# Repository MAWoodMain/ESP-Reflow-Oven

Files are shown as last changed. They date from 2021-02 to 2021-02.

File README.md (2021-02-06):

<!--
*** Thanks for checking out the Best-README-Template. If you have a suggestion
*** that would make this better, please fork the repo and create a pull request
*** or simply open an issue with the tag "enhancement".
*** Thanks again! Now go create something AMAZING! :D
***
***
***
*** To avoid retyping too much info. Do a search and replace for the following:
*** github_username, repo_name, twitter_handle, email, project_title, project_description
-->

<!--
*** This readme is based on the template from this github project
*** https://github.com/othneildrew/Best-README-Template
-->

<!-- PROJECT SHIELDS -->
<!--
*** I'm using markdown "reference style" links for readability.
*** Reference links are enclosed in brackets [ ] instead of parentheses ( ).
*** See the bottom of this document for the declaration of the reference variables
*** for contributors-url, forks-url, etc. This is an optional, concise syntax you may use.
*** https://www.markdownguide.org/basic-syntax/#reference-style-links
-->

<br />
<p align="center">

  <h3 align="center">ESP Reflow Oven</h3>

  <p align="center">
    A retro fit of a Lidl middle aisle mini oven into a home reflow oven
  </p>
</p>

<!-- TABLE OF CONTENTS -->
<details open="open">
  <summary><h2 style="display: inline-block">Table of Contents</h2></summary>
  <ol>
    <li>
      <a href="#about-the-project">About The Project</a>
      <ul>
        <li><a href="#objectives">Objectives</a></li>
        <li><a href="#component-selection">Component Selection</a></li>
      </ul>
    </li>
    <li>
      <a href="#the-build">The Build</a>
      <ul>
        <li><a href="#components">Components</a></li>
        <li><a href="#assembly">Assembly</a></li>
      </ul>
    </li>
    <li><a href="#the-final-product">The Final Product</a></li>
    <li><a href="#reflections">Reflections</a></li>
    <li><a href="#license">License</a></li>
  </ol>
</details>

<!-- ABOUT THE PROJECT -->
## About The Project
This project came about on a friday night trip to lidl in the UKs second lockdown. I spotted that lidl were selling mini ovens in the middle aisle for a meagre £25 (~$35), having seen many online creators doing their own homemade reflow ovens based on similar toaster ovens I though it would be a worthy weekend project.  
Naturally after getting home from lidl and putting away all the chilled and frozen foods I went straight into a teardown to see how this thing was put together, the original oven had 3 dials on the front:
* Temperature
* Mode (top/bottom/both elements)
* Timer

Under the hood there was practically nothing just a large void in the case with a few wires going to the elements, the temperature control was a simple bimetallic strip temeperature control which seems to operate based on the temperature in the chamber next to the oven? Not sure how that could even work properly, either way its going into the bin. Similar story for the mode switch, it just switches in and out elements based on the selection, this will not be required either.

After they were removed I was left with the mains input going through a thermal fuse and into a timer switch, I will keep the timer switch to I can set an automatic off when using the unit under computer control. Also this timer switch makes a rather satisfying ding sound when it turns off, I would hate to lose such an important feature...

<!-- OBJECTIVES -->
### Objectives
Had only a few key objectives when I started this project:

* All the mechanical components should be 3D printable using FDM technology.

* I wanted to utilise ESPHome as I have been following some creators project using it, and I was keen to give it a go.

* I wanted the SMT components on the PCB to be assembled by JLC assembly, I know this one sounds a bit weird given I am constructing a reflow oven, but it honestly is often cheaper to have components assembled at JLCPCB rather than ordering them, paying shipping for both PCBs and components then organising paste and a stencil. This oven if for when I have to use components not available for this service and for special cases.

* I needed the oven to follow a simple reflow curve, doesn't need to be prefect but it must work for basic board with normal components.

* I also wanted to try out a Nextion display as I had also seen a few videos by [Vaclav Chaloupka](https://www.youtube.com/user/bruxy70) making some cool home assistant home control panels using the modules.

* Finally I wanted to keep all the original products safety features in place so I don't create a major fire hazard.

<!-- COMPONENT SELECTION -->
### Component Selection

I knew this project would involve working with mains electricity so I made sure to choose components with recognisable approvals and safety certifications for the mains side of the electronics. For that reason I chose a [meanwell isolated AC to DC converter](https://www.meanwell.com/Upload/PDF/IRM-05/IRM-05-SPEC.PDF) to power the low voltage side of the electronics.

The heating elements were tested and found to draw around 600 Watts each which in the UK is around 2.5-3 Amps, the switching component selected for this load was a 5 Amp solid state relay. Specifically I made sure to select a zero crossing SSR as with resistive loads it is better for the powerline quality in the house as it avoids harsh mid phase loading. A [CX240D5](http://www.crydom.com/en/products/catalog/cx-series-ac-pcb-mount.pdf) was used as it was easily available and has approvals several reputable approvals (UL, CSA and CE).

A supplementary on board fuse holder and fuse was included in the design just in case the plug fuse is especially slow or overrated.

The low voltage side will be an ESP32, some thermocouple inputs and a DC output to allow for a fan in the future if required to cool the electronics.

For the thermocouple inputs I have very few ICs to choose from as JLC Assembly did not seem to have many available, I settled on the [MAX31855](https://datasheets.maximintegrated.com/en/ds/MAX31855.pdf) which includes cold junction compensation and requires no external components to work aside from basic decoupling. It uses SPI to send data back to the MCU, it has no settings to configure and does not support receiving data over SPI.

The fan output is a 5V power output which consists of a P-Channel MOSFET and a NPN drive transistor for the gate. This output can only support about 0.5A output as the meanwell power supply is only rated for 1A and the ESP32 required 0.5A.

Below is the 3D model of the PCB in the Kicad 3D viewer:

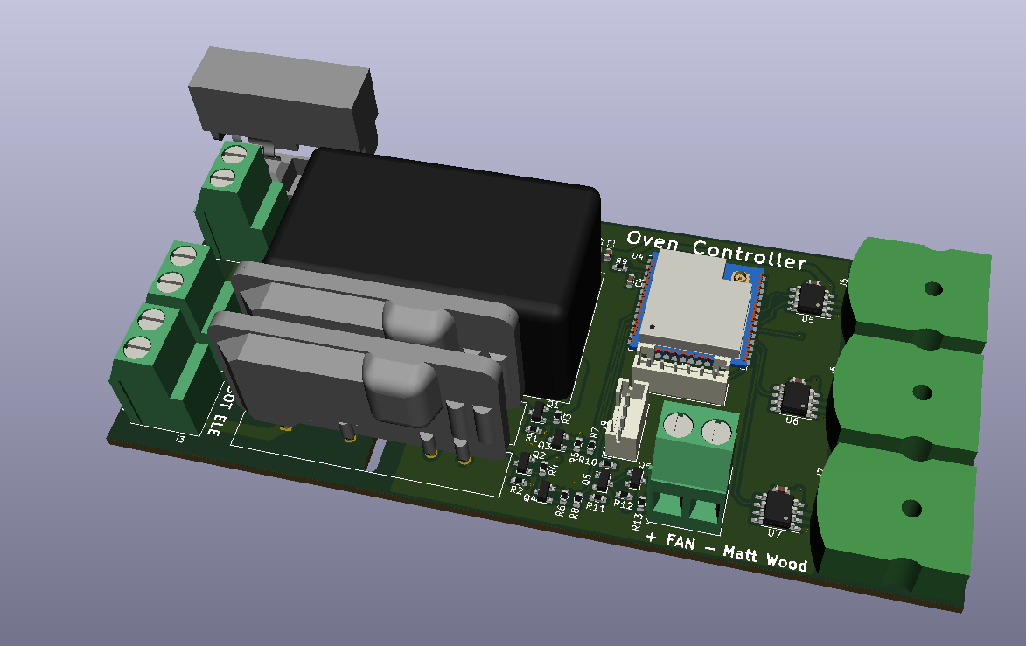
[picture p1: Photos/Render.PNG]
The PCBA


<!-- THE BUILD -->
## The Build

<!-- COMPONENTS -->
### Components

In addition to the assembled PCB discussed above and the 3D printed parts, a few extra components are required:
* 1 x u.FL to SMA pig tail to allow for an external antenna for the WiFi.
* 1 x SMA 2.4 GHz antenna
* 1 x USB to UART module (3.3V logic) to program the ESP and Nextion display
* 1x Nextion NX4832K035 display module
* 1x Custom cable to connect the nextion display to the PCB (JST-PH)
* 2x bead K type thermocouples
* Optional 1x high mass K type thermocouple for chamber air temperature

<!-- ASSEMBLY -->
### Assembly
The PCBs arrived SMT complete from JLCPCB, the THT components were hand soldered in to finish the PCBA off.
At this point it is worth getting the firmware uploaded into the ESP32, after the first firmware is loaded OTA updating is trivial using the ESPHome home assistant plugin.

It is also worth preparing the Nextion display module, I uploaded the firmware to the display using a USB to UART module and the nextion editor software.

As discussed in the project intro the original mode and temperature knobs were removed. 
Next some stand offs were mounted in the space next to the heating chamber to affix the PCB to.
The PCB was mounted and custom cables were crimped to connect up the mains input and heating elements.
Some holes were drilled to allow the thermocouples into the heated chamber one on the top of the right side and one on the bottom.

A hole was drilled for the SMA connector on the top and the u.FL end was plugged into the ESP32 module.

Next the 3D printed LCD mount was screwed into the front panel using the original self tapping screws which held the old controls on. The LCD was itself screwed into the mount using M3x10mm pan head bolts and the cable was run back to the main PCB. The LCD cover was pressed on to finish off the front. I discovered you must take care pressing this cover on as if you press it on too far it triggers the resistive touch screen on the nextion module.

Below is a photo of the electronics compartment, please don't judge the wire runs too heavily as it has been improved since.
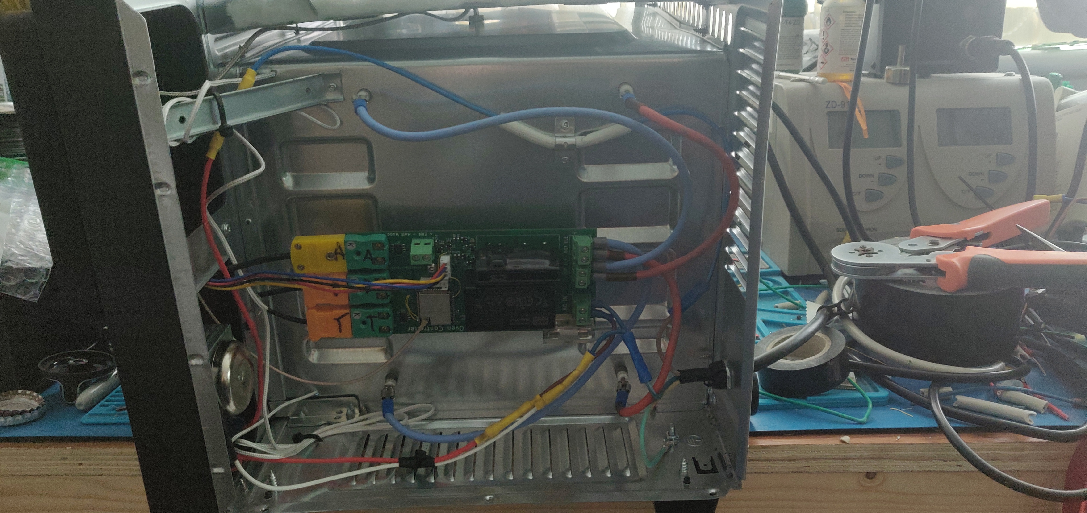
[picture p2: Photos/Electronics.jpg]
Electronics


Once the assembly was complete the PIDs loops require tuning so I attached the top and bottom thermocouples to a blank PCB and ran the auto tune routine for both the top and bottom PID control loops.
These values were saved into the ESPHome YAML so they persist though reboot.

<!-- THE FINAL PRODUCT -->
## The Final Product
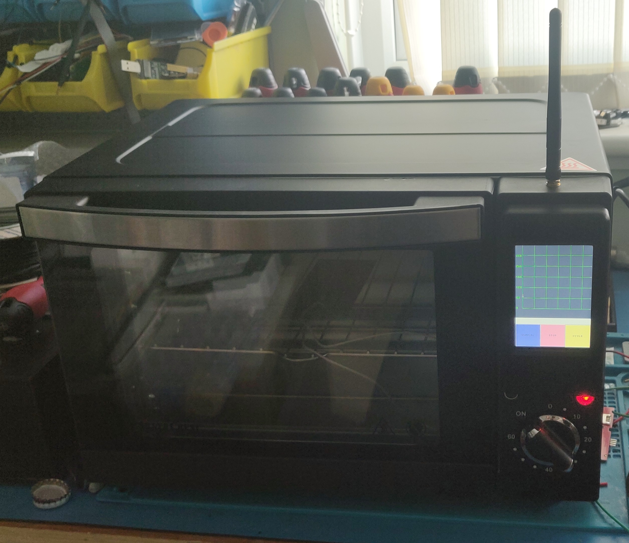
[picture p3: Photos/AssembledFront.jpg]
The final oven

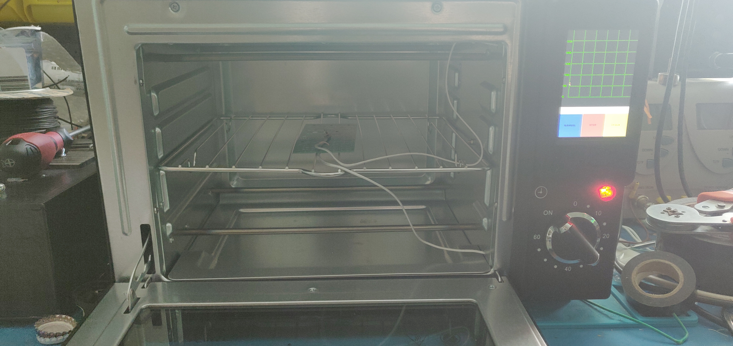
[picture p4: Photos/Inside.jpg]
The inside

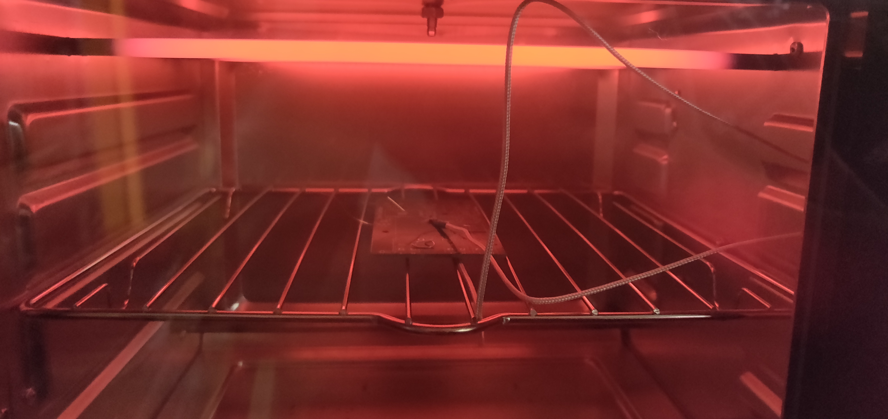
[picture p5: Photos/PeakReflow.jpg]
Mid reflow

<!-- REFLECTIONS -->
## Reflections

I am happy with the final product I think the outside looks very clean and the interface is simple and intuitive.
There are a few issues I ran into during this project:
* Two PID loops, since I went with independent top and bottom heat controls I have two PID loops for the top and bottom systems but since these two systems are used simultaneously they are not independent closed loop systems. The issue with this is that the PID settings do not account properly the other loop existing and thus tend to overshoot the set temperature when they are used together. For reflow I have not found a 5 degree overshoot to be a problem but for some use cases I could see it being an issue. I would propose two possible solutions: You could either combine the two elements and control them as a single large element in a single PID loop or you could use a more sophisticated control system which accounted for the second elements influence.

* Dependence on Home assistant, in the way I am currently controlling it the oven relys on HASS to orchastrate the reflow cycle, if the connection to HASS is lost the oven could be left on at the set temperature for too long. Also it means if HASS is unavailable the cycle button does not work properly. This could be resolved by hard coding the cycle into the ESPHome config, but I have not done this yet.

* Cost, this project was started because of the cheapness of the oven but untimately its cost mostly came in the PCBA price. The total price of the PCB was around £17 for the PCBs from JLC (part assembled) and around £35 of THT parts from Farnell for a total cost of £52 (parts) + £25 (oven) = £77 (~$105). I don't feel I over spent given the capability of this oven but it is slightly more then I though it would cost. The main cost issue was in the farnell parts but this was caused by the safe main voltage components, so it is likely unavoidable.

<!-- LICENSE -->
## License

Distributed under the MIT License. See `LICENSE` for more information.

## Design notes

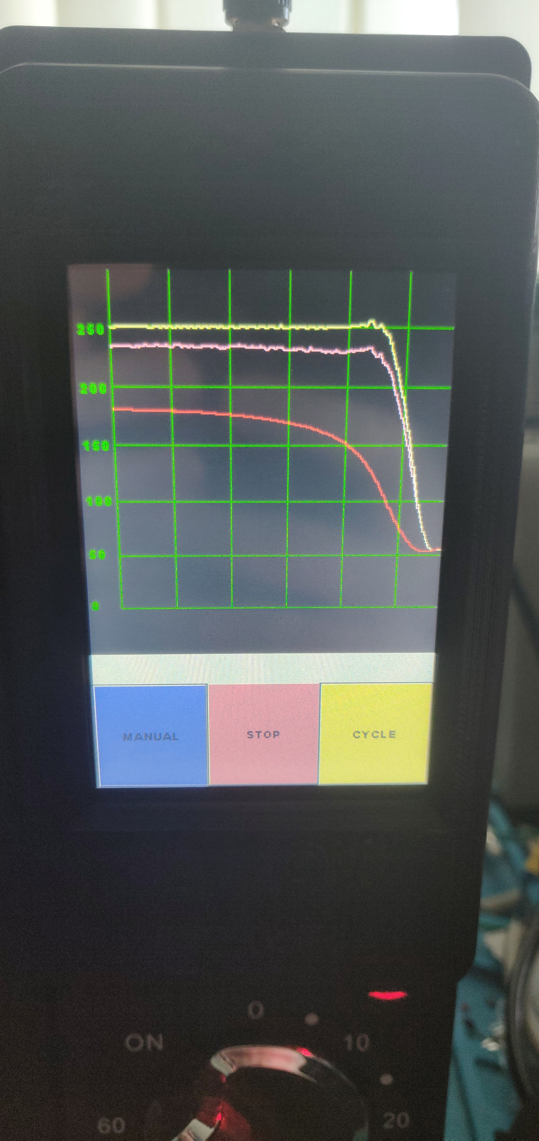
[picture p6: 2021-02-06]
Photos/DisplayGraph.jpg

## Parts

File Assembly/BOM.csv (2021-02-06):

Comment | Designator | Footprint | LCSC Part #
10uF Unpolarized capacitor | C1,C2 | C_0805_2012Metric | C15850
100nF Unpolarized capacitor, small symbol | C3,C4,C5,C6,C7 | C_0603_1608Metric | C14663
696101000002 | J4 | 696101000002
AO3401A -4.0A Id, -30V Vds, P-Channel MOSFET, SOT-23 | Q1,Q2,Q6 | SOT-23 | C15127
BC847 0.1A Ic, 45V Vce, NPN Transistor, SOT-23 | Q3,Q4,Q5 | SOT-23 | C426568
10K Resistor, small symbol | R1,R2,R3,R4,R5,R6,R9,R11,R12,R13 | R_0603_1608Metric | C25804
1K Resistor, small symbol | R7,R8,R10 | R_0603_1608Metric | C21190
AMS1117-3.3 1A Low Dropout regulator, positive, 3.3V fixed output, SOT-223 | U3 | SOT-223-3_TabPin2 | C6186
ESP32-WROOM-32U RF Module, ESP32-D0WD SoC, Wi-Fi 802.11b/g/n, Bluetooth, BLE, 32-bit, 2.7-3.6V, external antenna, SMD | U4 | ESP32-WROOM-32U | C328062
MAX31855KASA Cold Junction K-type Termocouple Interface, SPI, SO8 | U5,U6,U7 | SOIC-8_3.9x4.9mm_P1.27mm | C52028

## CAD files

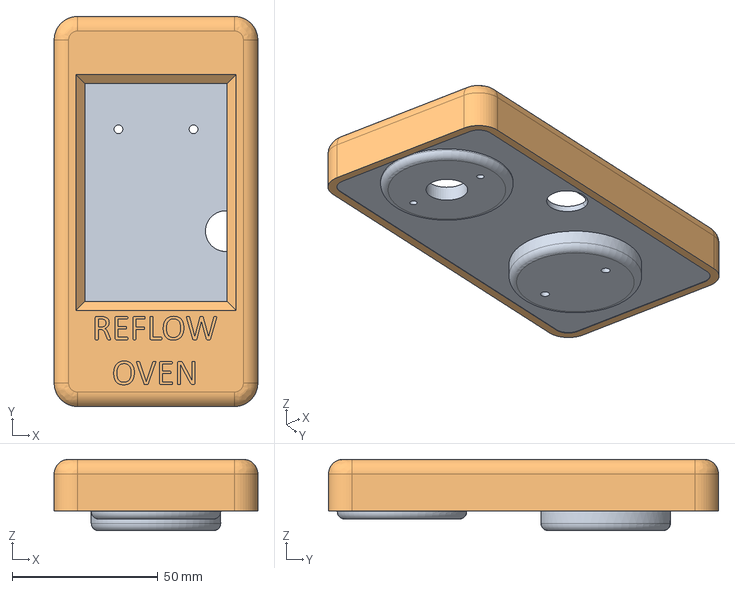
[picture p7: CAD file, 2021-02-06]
3D Printed Parts/LCD Assembly v3.step
70.0 x 134.0 x 24.5 mm
LCD Mount
LCD Cover

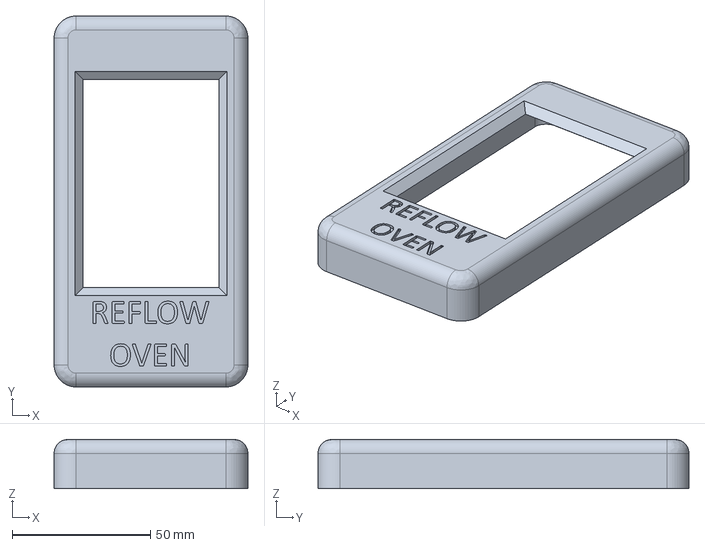
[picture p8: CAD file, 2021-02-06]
3D Printed Parts/LCD Cover v3.step
70.0 x 134.0 x 17.7 mm

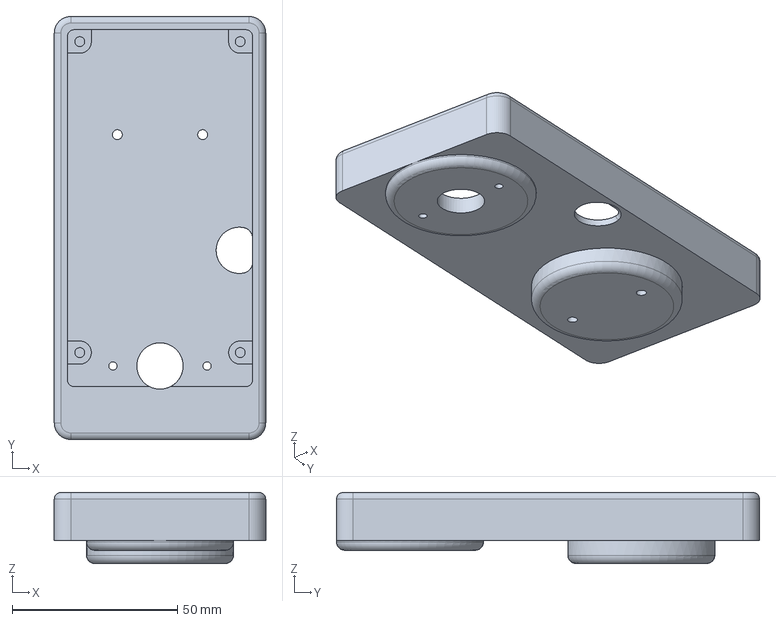
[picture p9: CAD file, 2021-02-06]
3D Printed Parts/LCD Mount v5.step
64.0 x 128.0 x 21.5 mm

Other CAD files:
3D Printed Parts/LCD Cover v3.f3d
3D Printed Parts/LCD Cover v3.stl
3D Printed Parts/LCD Mount v5.f3d
3D Printed Parts/LCD Mount v5.stl

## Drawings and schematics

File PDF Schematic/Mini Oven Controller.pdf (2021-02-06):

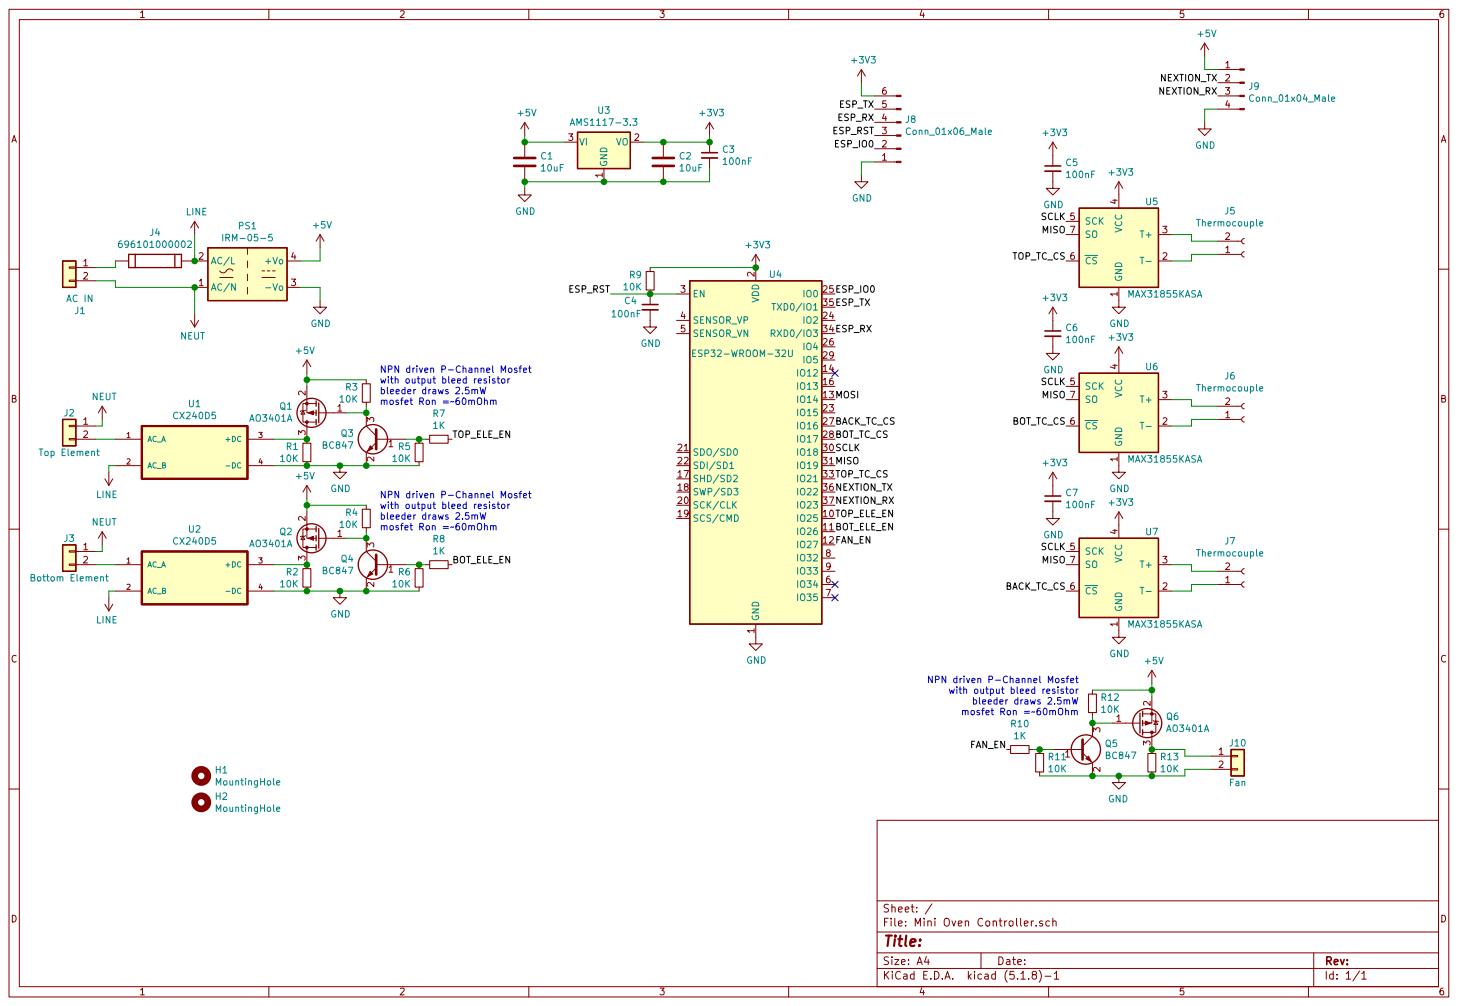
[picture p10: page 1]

4 SCK 5 CS 6 SO 7 U5 MAX31855KASA GND
SCLK
TOP_TC_CS MISO

4 SCK 5 CS 6 SO 7 U6 MAX31855KASA GND

2 SCK/CLK 20 SDO/SD0 21 SDI/SD1 22

NPN driven P-Channel Mosfet with output bleed resistor bleeder draws 2.5mW

4 SCK 5 CS 6 SO 7 U7 MAX31855KASA GND

Id: 1/1 Title: File: Mini Oven Controller.sch Sheet: /

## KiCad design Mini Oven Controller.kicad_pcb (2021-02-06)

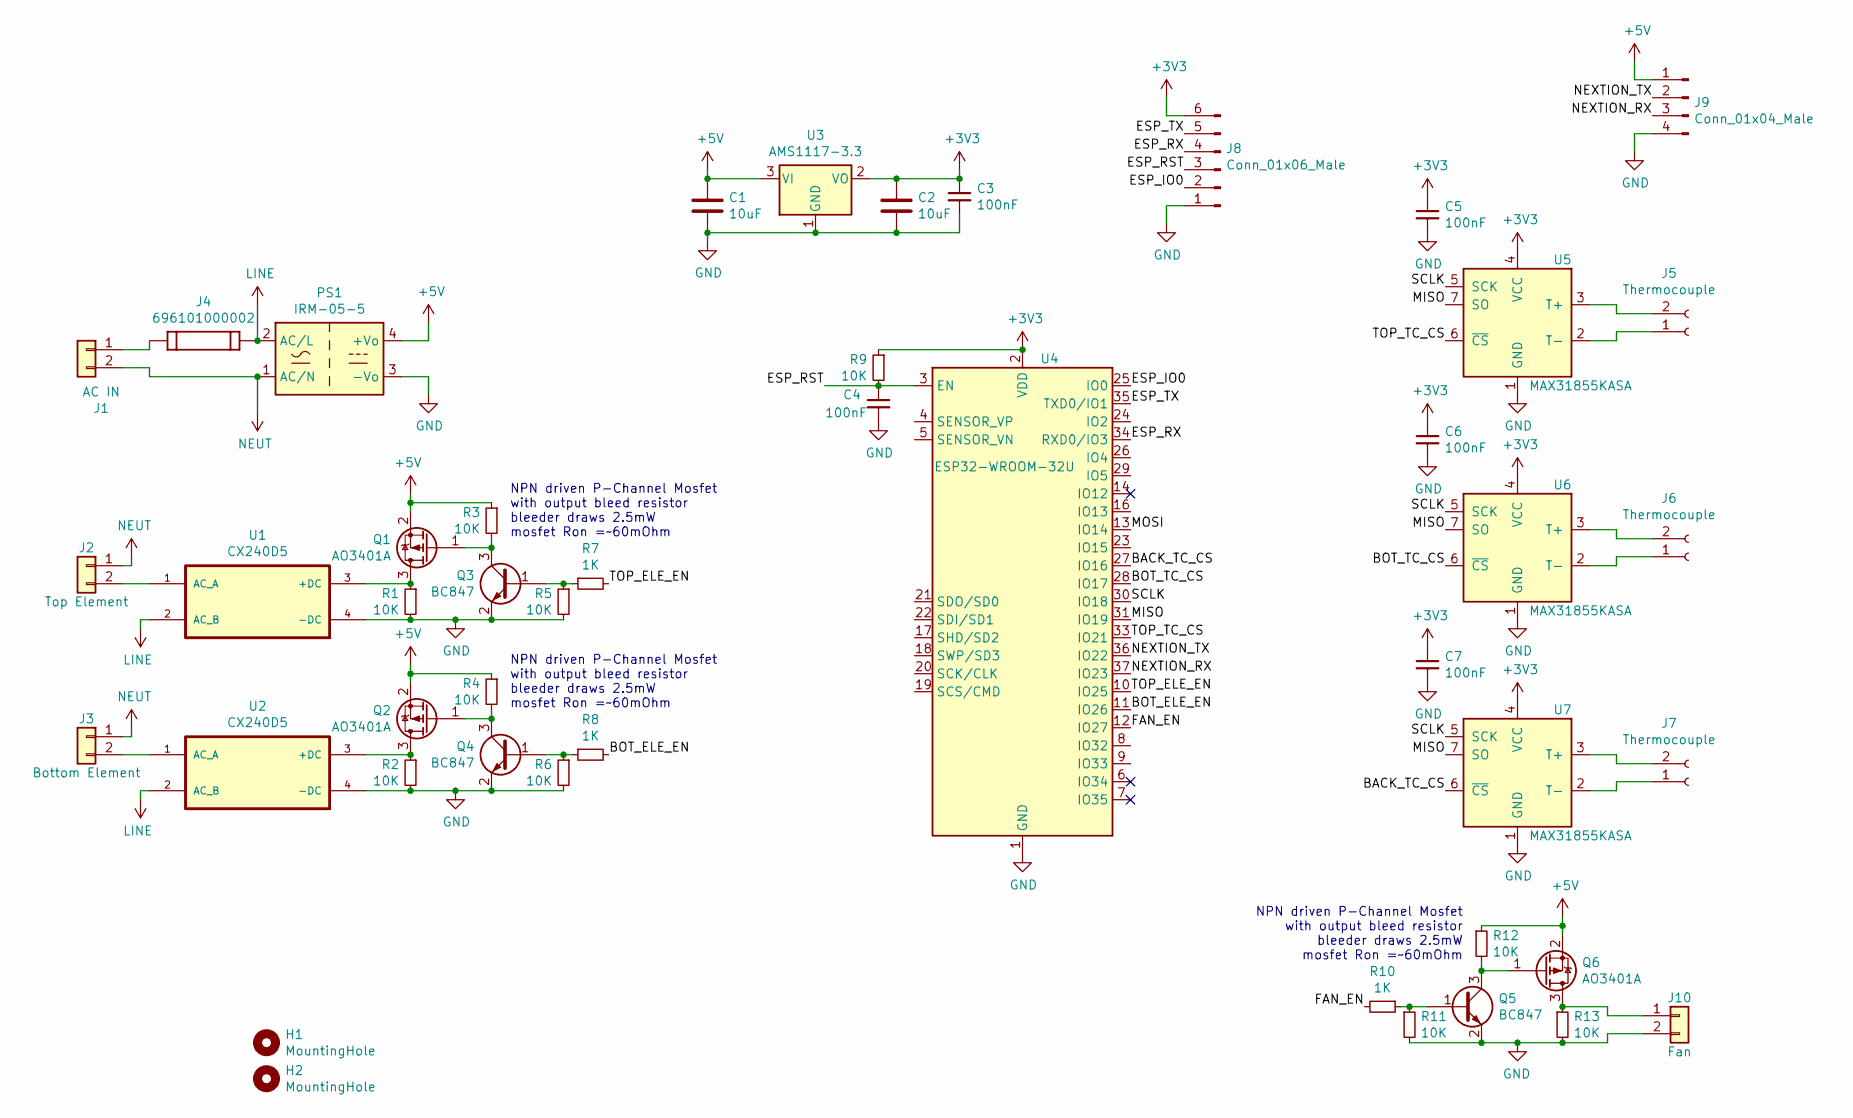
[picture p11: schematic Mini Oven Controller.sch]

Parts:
C1, C2: 10uF; C_0805_2012Metric; LCSC Part C15850
C3, C4, C5, C6, C7: 100nF; C_0603_1608Metric; LCSC Part C14663
H1, H2: MountingHole; MountingHole_3.2mm_M3; JLCPCB BOM 0
J1: AC IN; TerminalBlock_Phoenix_MKDS-3-2-5.08_1x02_P5.08mm_Horizontal; JLCPCB BOM 0
J2: Top Element; TerminalBlock_Phoenix_MKDS-3-2-5.08_1x02_P5.08mm_Horizontal; JLCPCB BOM 0
J3: Bottom Element; TerminalBlock_Phoenix_MKDS-3-2-5.08_1x02_P5.08mm_Horizontal; JLCPCB BOM 0
J4: 696101000002; PART-NUMBER 696101000002
J5, J6, J7: Thermocouple; IM-K-PCB; JLCPCB BOM 0
J8: Conn_01x06_Male; JST_PH_B6B-PH-K_1x06_P2.00mm_Vertical; JLCPCB BOM 0
J9: Conn_01x04_Male; JST_PH_B4B-PH-K_1x04_P2.00mm_Vertical; JLCPCB BOM 0
J10: Fan; TerminalBlock_Phoenix_MKDS-3-2-5.08_1x02_P5.08mm_Horizontal; JLCPCB BOM 0
PS1: IRM-05-5; Converter_ACDC_MeanWell_IRM-05-xx_THT; JLCPCB BOM 0
Q1, Q2, Q6: AO3401A; SOT-23; LCSC Part C15127
Q3, Q4, Q5: BC847; SOT-23; LCSC Part C426568
R1, R2, R3, R4, R5, R6, R9, R11, R12, R13: 10K; R_0603_1608Metric; LCSC Part C25804
R7, R8, R10: 1K; R_0603_1608Metric; LCSC Part C21190
U1, U2: CX240D5; CRYDOM_CX240D5; JLCPCB BOM 0
U3: AMS1117-3.3; SOT-223-3_TabPin2; LCSC Part C6186
U4: ESP32-WROOM-32U; LCSC Part C328062
U5, U6, U7: MAX31855KASA; SOIC-8_3.9x4.9mm_P1.27mm; LCSC Part C52028

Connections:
+3V3: C2.1, C3.1, C5.1, C6.1, C7.1, J8.6, R9.1, U3.2 (VO), U4.2 (VDD), U5.4 (VCC), U6.4 (VCC), U7.4 (VCC)
+5V: C1.1, J9.1, PS1.4 (+Vo), Q1.2 (S), Q2.2 (S), Q6.2 (S), R3.1, R4.1, R12.1, U3.3 (VI)
/BACK_TC_CS: U4.27 (IO16), U7.6 (~CS~)
/BOT_ELE_EN: R8.2, U4.11 (IO26)
/BOT_TC_CS: U4.28 (IO17), U6.6 (~CS~)
/ESP_IO0: J8.2, U4.25 (IO0)
/ESP_RST: C4.1, J8.3, R9.2, U4.3 (EN)
/ESP_RX: J8.4, U4.34 (RXD0/IO3)
/ESP_TX: J8.5, U4.35 (TXD0/IO1)
/FAN_EN: R10.2, U4.12 (IO27)
/MISO: U4.31 (IO19), U5.7 (SO), U6.7 (SO), U7.7 (SO)
/MOSI: U4.13 (IO14)
/NEXTION_RX: J9.3, U4.37 (IO23)
/NEXTION_TX: J9.2, U4.36 (IO22)
/SCLK: U4.30 (IO18), U5.5 (SCK), U6.5 (SCK), U7.5 (SCK)
/TOP_ELE_EN: R7.2, U4.10 (IO25)
/TOP_TC_CS: U4.33 (IO21), U5.6 (~CS~)
GND: C1.2, C2.2, C3.2, C4.2, C5.2, C6.2, C7.2, J8.1, J9.4, J10.2, PS1.3 (-Vo), Q3.2 (E), Q4.2 (E), Q5.2 (E), R1.2, R2.2, R5.2, R6.2, R11.2, R13.2, U1.4 (-DC), U2.4 (-DC), U3.1 (GND), U4.1 (GND), U4.15 (GND), U4.38 (GND), U4.39 (GND), U5.1 (GND), U6.1 (GND), U7.1 (GND)
LINE: J4.2, PS1.2 (AC/L), U1.2 (AC_B), U2.2 (AC_B)
NEUT: J1.2, J2.1, J3.1, PS1.1 (AC/N)
unnamed: J1.1, J4.1
unnamed: J2.2, U1.1 (AC_A)
unnamed: J3.2, U2.1 (AC_A)
unnamed: J5.1, U5.2 (T-)
unnamed: J5.2, U5.3 (T+)
unnamed: J6.1, U6.2 (T-)
unnamed: J6.2, U6.3 (T+)
unnamed: J7.1, U7.2 (T-)
unnamed: J7.2, U7.3 (T+)
unnamed: J10.1, Q6.3 (D), R13.1
unnamed: Q1.1 (G), Q3.3 (C), R3.2
unnamed: Q1.3 (D), R1.1, U1.3 (+DC)
unnamed: Q2.1 (G), Q4.3 (C), R4.2
unnamed: Q2.3 (D), R2.1, U2.3 (+DC)
unnamed: Q3.1 (B), R5.1, R7.1
unnamed: Q4.1 (B), R6.1, R8.1
unnamed: Q5.1 (B), R10.1, R11.1
unnamed: Q5.3 (C), Q6.1 (G), R12.2

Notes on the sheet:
NPN driven P-Channel Mosfet with output bleed resistor bleeder draws 2.5mW mosfet Ron =~~60mOhm

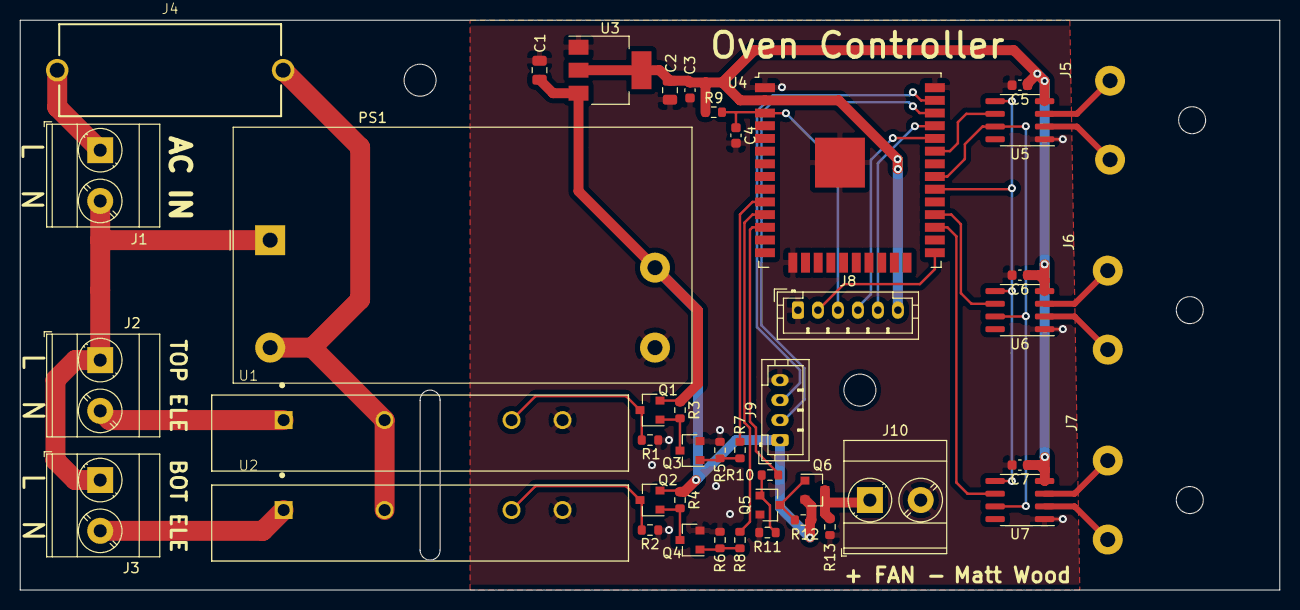
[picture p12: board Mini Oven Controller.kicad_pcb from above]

Board: 2 copper layers, 126.0 x 57.0 mm, 46 parts (0 on the bottom side), 37 nets.

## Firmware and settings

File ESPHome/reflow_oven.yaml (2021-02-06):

esphome:
  name: reflow_oven
  platform: ESP32
  board: esp-wrover-kit

wifi:
  # Configure home wifi settings here
  ssid: "WIFI SSID HERE"
  password: "WIFI PASSWORD HERE"

  # Enable fallback hotspot (captive portal) in case wifi connection fails
  ap:
    ssid: "Reflow Oven Fallback Hotspot"
    password: "FALLBACK PASSWORD HERE"

captive_portal:

uart:
  id: nextion_uart
  rx_pin: GPIO22
  tx_pin: GPIO23
  baud_rate: 9600

spi:
  miso_pin: GPIO19
  mosi_pin: GPIO14
  clk_pin: GPIO18

globals:
  # Keep track of what page the nextion dispaly is showing
  - id: nextion_page
    type: int
    initial_value: '0'

binary_sensor:
  - platform: nextion
    page_id: 0
    component_id: 3
    id: manual_button
    on_press:
      then:
        - logger.log:
            format: "MANUAL PRESSED"
        - globals.set:
            id: nextion_page
            value: '2'
  - platform: nextion
    page_id: 0
    component_id: 5
    id: cycle_button
    on_press:
      then:
        - logger.log:
            format: "CYCLE PRESSED"
  # This button runs a custom script on homeassistant that produces a reflow cycles
        - homeassistant.service:
            service: script.1610815555029
        - globals.set:
            id: nextion_page
            value: '0'
  - platform: nextion
    page_id: 0
    component_id: 4
    id: stop_button
    on_press:
      then:
        - logger.log:
            format: "STOP PRESSED"
        - climate.control:
            id: top_pid
            mode: "OFF"
            target_temperature: 0°C
        - climate.control:
            id: bot_pid
            mode: "OFF"
            target_temperature: 0°C
        - globals.set:
            id: nextion_page
            value: '0'
  - platform: nextion
    page_id: 2
    component_id: 12
    id: bot_off_button
    on_press:
      then:
        - logger.log:
            format: "BOT OFF PRESSED"
        - climate.control:
            id: bot_pid
            mode: "OFF"
            target_temperature: 0°C
        - globals.set:
            id: nextion_page
            value: '0'
  - platform: nextion
    page_id: 2
    component_id: 13
    id: bot_100_button
    on_press:
      then:
        - logger.log:
            format: "BOT 150 PRESSED"
        - climate.control:
            id: bot_pid
            mode: "AUTO"
            target_temperature: 100°C
        - globals.set:
            id: nextion_page
            value: '0'
  - platform: nextion
    page_id: 2
    component_id: 14
    id: bot_150_button
    on_press:
      then:
        - logger.log:
            format: "BOT 150 PRESSED"
        - climate.control:
            id: bot_pid
            mode: "AUTO"
            target_temperature: 150°C
        - globals.set:
            id: nextion_page
            value: '0'
  - platform: nextion
    page_id: 2
    component_id: 15
    id: bot_200_button
    on_press:
      then:
        - logger.log:
            format: "BOT 200 PRESSED"
        - climate.control:
            id: bot_pid
            mode: "AUTO"
            target_temperature: 200°C
        - globals.set:
            id: nextion_page
            value: '0'
  - platform: nextion
    page_id: 2
    component_id: 16
    id: bot_250_button
    on_press:
      then:
        - logger.log:
            format: "BOT 250 PRESSED"
        - climate.control:
            id: bot_pid
            mode: "AUTO"
            target_temperature: 250°C
        - globals.set:
            id: nextion_page
            value: '0'
            
  - platform: nextion
    page_id: 2
    component_id: 7
    id: top_off_button
    on_press:
      then:
        - logger.log:
            format: "TOP OFF PRESSED"
        - climate.control:
            id: top_pid
            mode: "OFF"
            target_temperature: 0°C
        - globals.set:
            id: nextion_page
            value: '0'
  - platform: nextion
    page_id: 2
    component_id: 8
    id: top_100_button
    on_press:
      then:
        - logger.log:
            format: "BOT 150 PRESSED"
        - climate.control:
            id: top_pid
            mode: "AUTO"
            target_temperature: 100°C
        - globals.set:
            id: nextion_page
            value: '0'
  - platform: nextion
    page_id: 2
    component_id: 9
    id: top_150_button
    on_press:
      then:
        - logger.log:
            format: "BOT 150 PRESSED"
        - climate.control:
            id: top_pid
            mode: "AUTO"
            target_temperature: 150°C
        - globals.set:
            id: nextion_page
            value: '0'
  - platform: nextion
    page_id: 2
    component_id: 10
    id: top_200_button
    on_press:
      then:
        - logger.log:
            format: "BOT 200 PRESSED"
        - climate.control:
            id: top_pid
            mode: "AUTO"
            target_temperature: 200°C
        - globals.set:
            id: nextion_page
            value: '0'
  - platform: nextion
    page_id: 2
    component_id: 11
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

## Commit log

2021-02-06 Initial upload of project files, PCB updated to correct prototype mistake. ESP home YAML file and nextion display config included.
    [BOM.csv, JLC_POS_TOP.csv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]
2021-02-06 saved and exited pcbnew
    [Mini Oven Controller.kicad_pcb]
2021-02-06 Added in 3D printed part files in F3D, STEP and STL format
    [LCD Assembly v3.step, LCD Cover v3.f3d, LCD Cover v3.step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]
2021-02-06 Added a PDF schematic
